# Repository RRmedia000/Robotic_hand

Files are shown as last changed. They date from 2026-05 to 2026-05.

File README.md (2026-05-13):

# 3D Printed Robotic Hand

A servo-driven robotic hand built with a 3D printed structure, fishing wire tendons, and an Arduino Mega. Pressing a button closes the hand by pulling four servos simultaneously.

---

## Why I built this

This project started as a practical portfolio piece — I wanted to build something real and hands-on that showed what I could do with electronics, 3D printing, and code all in one. A robotic hand felt like the perfect challenge.

Beyond the portfolio side of things, I'm releasing this completely free because I genuinely want to help the community. If this helps someone learn Arduino, get into robotics, or just have fun building something cool, that's more than enough for me. It was a great project to work on and I hope others get as much out of it as I did.

---

## How it works

The hand is 3D printed and actuated by four micro servos connected to an Arduino Mega. Each finger is linked to its servo via fishing wire routed through the palm — when the servos rotate, they pull the wire and curl the fingers closed. Elastic tendons on the back of the hand act as passive supports, keeping the fingers extended in the open position and returning them when the servos release.

A single button on pin 13 triggers the whole hand to close. Releasing the button lets the back tendons pull the fingers back open.

---

## Hardware

| Component | Details |
|---|---|
| Microcontroller | Arduino Mega |
| Servos | 4× micro servos |
| Servo pins | 3, 7, 8, 10 |
| Button pin | 13 |
| Structure | 3D printed |
| Tendon (pull) | Fishing wire |
| Tendon (return) | Elastic on back of hand |

---
##3D Print
Export hand5.3mf **without** supports!!
## Wiring

- **Servos** — signal wires to pins 3, 7, 8, 10. Power (red) to 5V rail, ground (brown/black) to GND rail on breadboard.
- **Button** — one leg to pin 13, other leg to GND. Uses Arduino's internal pull-up resistor, no external resistor needed.
- **Power** — use an external 5V supply (2A or more) to power the servos. Connect the supply GND to the Arduino GND to share a common ground.

---

> If 90° doesn't fully close the fingers, increase the angle — servos typically go up to 180°. Tune each servo individually if the fingers close unevenly.

---

## Build notes

- Route the fishing wire carefully through the finger channels so it pulls straight without binding.
- Tension the back tendons so the hand rests fully open but isn't fighting the servos when closing.
- The Arduino Mega's pin 13 has an onboard LED tied to it — it will light up when the button is pressed. This is normal and harmless.

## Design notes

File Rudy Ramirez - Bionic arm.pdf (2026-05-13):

# IDL

Rudy's Exploration to a Bionic Arm
First Exploration

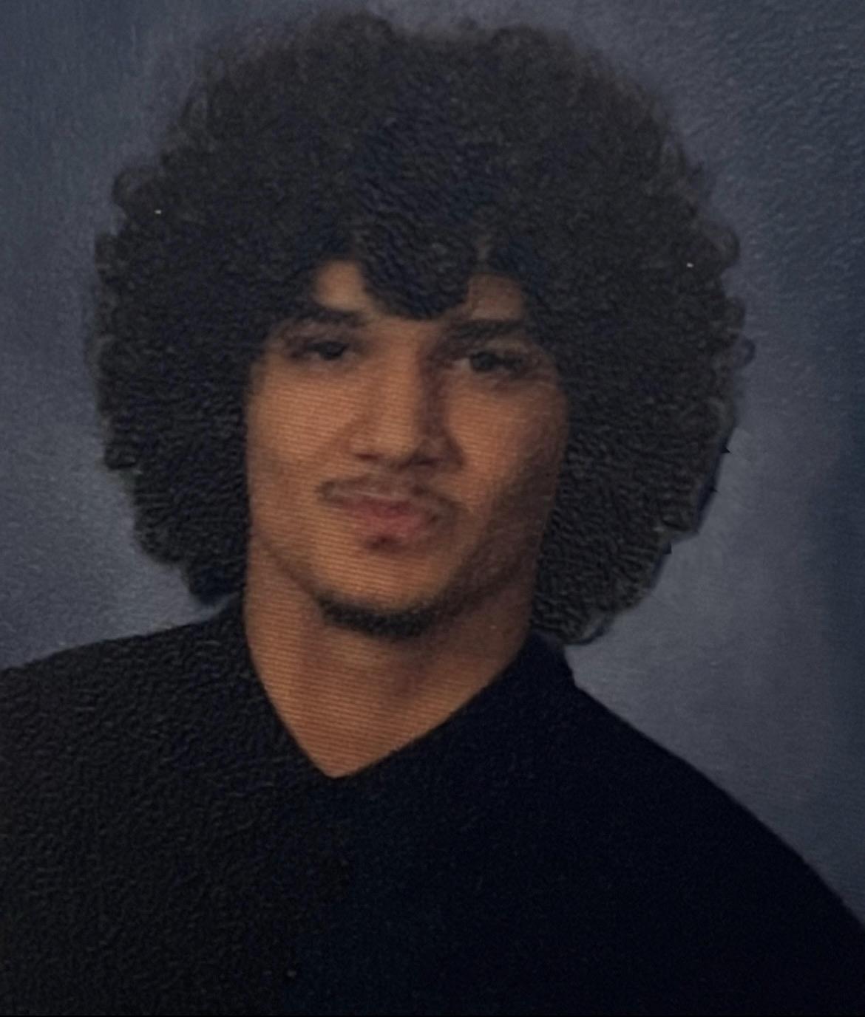
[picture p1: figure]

# Click here → linkedin (https://www.linkedin.com/in/rudy-ramirez-52a423335/)

### Introduction

Hello, my name is Rudy Ramirez. I am a student at Phoenix Coding Academy and an upcoming degree seeking mechanical engineering student at ASU. I am using this opportunity to get a feel for electrical components and what is possible with open source material. What I am trying to get from this project is electrical, software, 3D modeling, and component integration skills.

This project is my first hands-on exploration into robotics and bionics. Starting from zero knowledge of servo motors and mechanical actuation, I worked through research, design, and physical assembly to produce a functioning robotic hand controlled by an Arduino Mega. Every part of the process — from understanding how a real hand moves, to wiring electronics, to printing and assembling the structure — was a learning opportunity I took seriously.

The goal was never just to build something that looked like a hand. The goal was to understand why it works the way it does, and to build a foundation I can grow from as I move into mechanical engineering at ASU.

### Methodology

Understanding How a Hand Works

Before touching any hardware, I needed to understand the anatomy of a real hand — specifically what makes fingers move and what keeps them in position. I studied the mechanics of finger flexion and extension, focusing on how tendons pull the fingers closed and how the opposing tendons on the back of the hand return them to the open position.

From this research I understood that a tendon-driven design — where fishing wire acts as the flexor tendon and elastic cord on the back acts as the extensor — would be the most practical approach for a 3D printed hand at this scale.

Videos Referenced:

How Do Fingers Work? — Anatomy of the Hand and Tendons How Robotic Hands Mimic Human Movement

Articles Referenced:

Tendon-Driven Robotic Hands — ResearchGate

The Anatomy of Hand Movement — Khan Academy

### 3D Modeling and Printing

With the mechanical concept understood, I moved into 3D modeling the hand structure. The design needed to house four servo motors in the palm, route fishing wire cleanly through each finger channel, allow full range of motion without binding, and have anchor points on the back for the elastic return tendons.

The parts were printed and assembled before any electronics were attached, allowing me to verify that the finger motion was smooth and that the wire routing didn't bind at any joint.

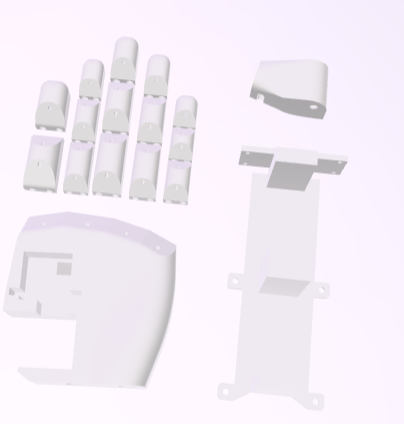
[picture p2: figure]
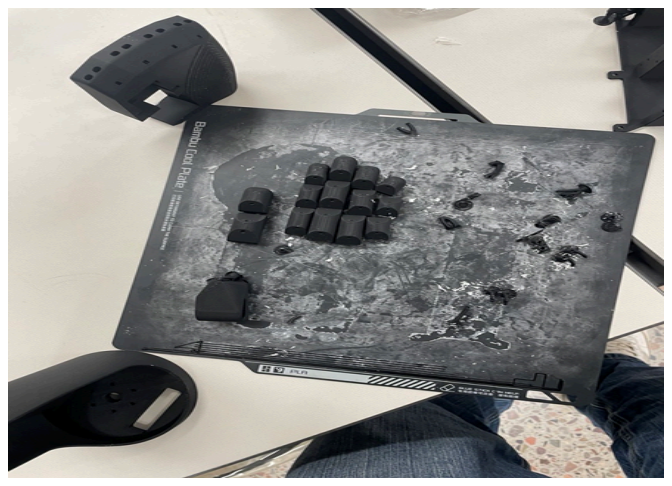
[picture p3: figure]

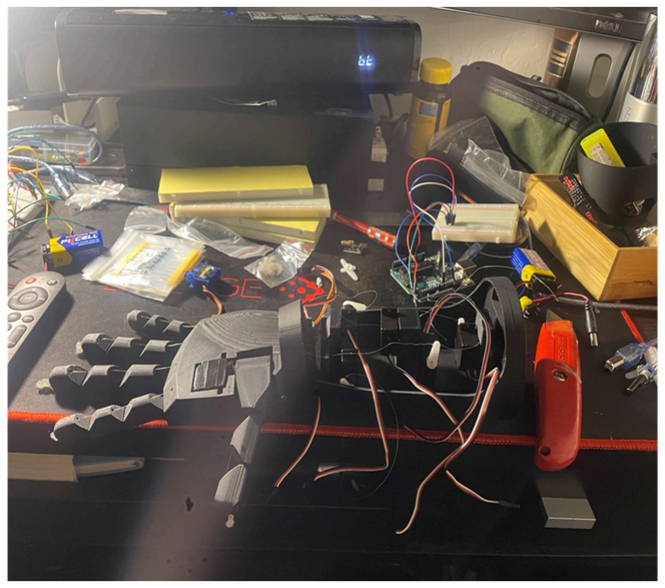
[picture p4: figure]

### Electronics and Wiring

Once the structure was printed and assembled, I wired the four micro servos to an Arduino Mega through a breadboard. An external 5V power supply powers the servos directly — running them off the Arduino's onboard 5V pin would damage the board under load. A shared ground between the supply and the Arduino is critical for the signal wires to work correctly.

A button on pin 13 triggers the hand to close. Pressing it rotates all four servos to 90 degrees, pulling the fishing wire and curling the fingers. Releasing the button lets the back tendons return the fingers to the open position.

Component | Pin
Servo 1 | 3
Servo 2 | 7
Servo 3 | 8
Servo 4 | 10
Button | 13

### Software

The code uses Arduino's built-in Servo library. The button uses INPUT_PULLUP so no external resistor is needed — the pin reads LOW when pressed, triggering all four servos to close simultaneously.

#include <Servo.h>

Servo s1, s2, s3, s4;

const int BUTTON_PIN = 13;

void setup() {

s1.attach(3); s2.attach(7);
s3.attach(8); s4.attach(10); pinMode(BUTTON_PIN, INPUT_PULLUP); s1.write(0); s2.write(0); s3.write(0); s4.write(0); }

void loop() {

if (digitalRead(BUTTON_PIN) == LOW) { s1.write(90); s2.write(90); s3.write(90); s4.write(90); } else {
s1.write(0); s2.write(0); s3.write(0); s4.write(0);
}
}

### Reflection

This project gave me direct experience in four areas I set out to develop: electrical wiring, software (Arduino C++), 3D modeling, and integrating all three into a working physical system. The biggest lesson was how much the mechanical design and the electronics depend on each other — a servo cannot do its job if the wire routing binds, and the code cannot help if the
ground is not shared correctly.

This is the first exploration. The next step is expanding toward a full bionic arm with more degrees of freedom, individual finger control, and eventually sensor feedback.

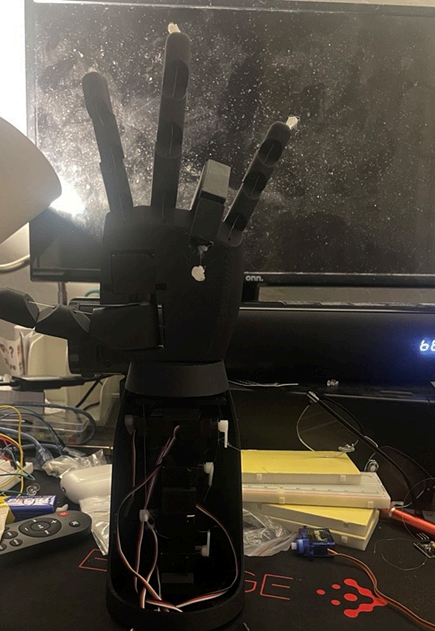
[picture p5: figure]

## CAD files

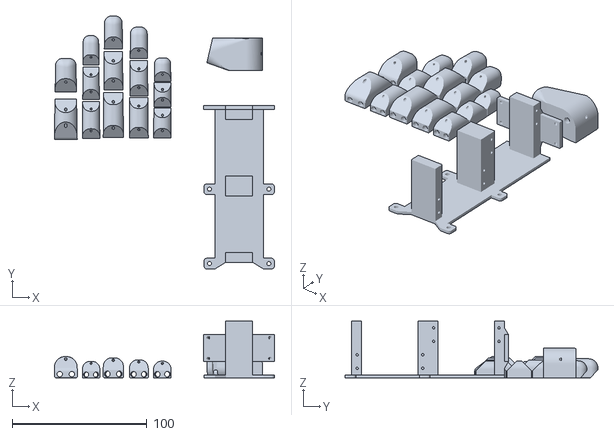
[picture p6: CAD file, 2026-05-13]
hand5thumb3q2.stl
163.2 x 187.4 x 42.1

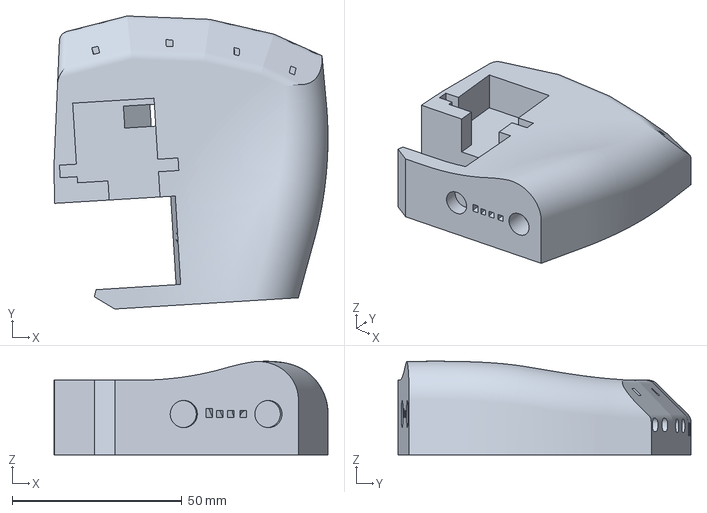
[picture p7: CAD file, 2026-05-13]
hand5.3mf
80.7 x 86.3 x 27.6 mm

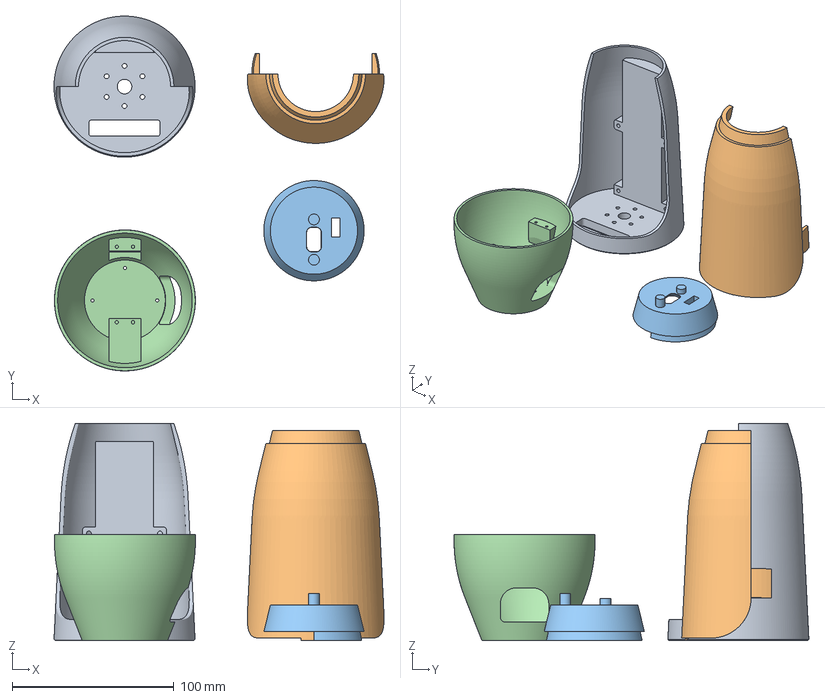
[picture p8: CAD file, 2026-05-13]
All_forearm.3mf
204.2 x 219.6 x 134.4 mm
forarm-9-2-1.stl
forarm-9-2-cover-1.stl
forarm-9-3-2.stl
forearm9-1-1.stl

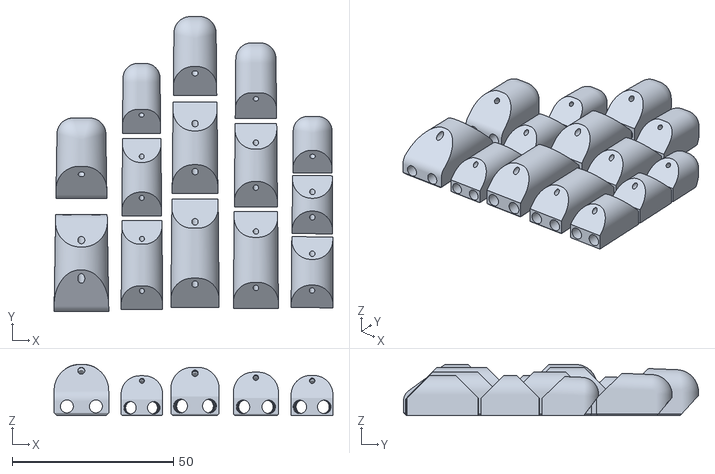
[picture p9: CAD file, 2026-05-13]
fingerdesign-all-2.stl
86.5 x 91.5 x 15.8
